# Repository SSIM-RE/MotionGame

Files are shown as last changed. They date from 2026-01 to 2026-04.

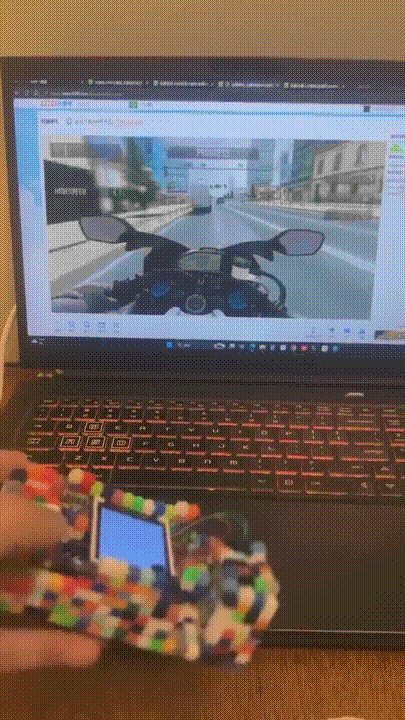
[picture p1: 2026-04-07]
img/控制.gif

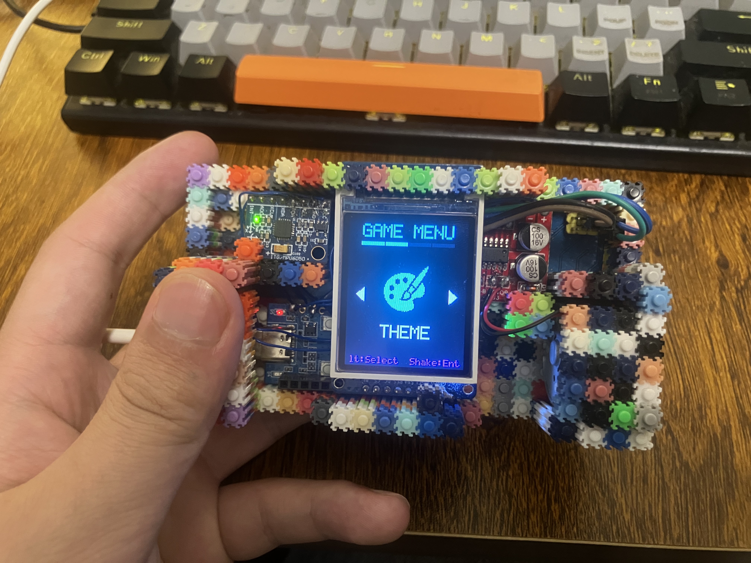
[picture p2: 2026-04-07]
img/微信图片_20260407233300_20_2.jpg

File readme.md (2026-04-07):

# MotionGame 🎮

> 基于 ESP32-C3 的体感游戏设备 + WiFi 无线键盘控制器





---

## 项目简介

MotionGame 是一款基于 ESP32-C3 的体感游戏设备，集成 MPU6050 六轴传感器，支持多款体感游戏。设备同时具备 **WiFi 无线键盘控制器** 功能，可以将倾斜、摇晃手势实时映射为键盘输入，控制 PC 上的应用程序。

---

## 硬件规格

| 组件 | 型号 | 说明 |
|---|---|---|
| MCU | ESP32-C3 | RISC-V 架构，160MHz，WiFi 内置 |
| IMU | MPU6050 | 6轴陀螺仪+加速度计，I2C 接口 |
| 屏幕 | ST7735 | 128×160 LCD，SPI 接口 |
| 震动 | L298N 马达驱动 | PWM 多段波形震动反馈 |
| 声音 | 蜂鸣器 | 多音符序列音效 |
| 供电 | USB-C | 5V/500m |

---

## 🎬 功能演示
*见img文件夹*
### 🖥️ 系统切换

系统

🖥️ 主题切换

主题

### 🎮 游戏

游戏

### ⌨️ 体感控制输入

控制

| 设备倾斜 | → | PC 按键 | 说明 |
|:---:|:-:|:---:|:-----:|
| 前倾 | → | ↑ | 向上 |
| 后倾 | → | ↓ | 向下 |
| 左倾 | → | ← | 向左 |
| 右倾 | → | → | 向右 |
| 摇晃 | → | A | 确认 |

---

## 功能模式

### 🎮 游戏模式

| 游戏 | 控制方式 | 说明 |
|---|---|---|
| 🐍 贪吃蛇 | 前后左右倾斜 | 经典贪吃蛇，体感控制方向 |
| ⚽ 平衡球 | 前后左右倾斜 | 控制小球滚动到目标区域 |
| 🏎️ 赛车 | Roll=加速/减速 Pitch=转向 | 伪3D 赛道，动态天空系统 |

### ⌨️ WiFi 控制器模式

将设备变为无线键盘，通过 UDP 发送按键事件到 PC。

| 倾斜方向 | 映射按键 |
|---|---|
| 右倾 (pitch ↑) | → (右箭头) |
| 左倾 (pitch ↓) | ← (左箭头) |
| 前倾 (roll ↑) | ↑ (上箭头) |
| 后倾 (roll ↓) | ↓ (下箭头) |
| 摇晃 | A (50ms 脉冲) |

进入模式时自动锁定基准姿态。

---

## 🏎️ 赛车游戏 - 伪3D 赛道实现详解

### 参考项目

本游戏的伪3D赛道实现参考自 [BojanSof/Pseudo3D-road](https://github.com/BojanSof/Pseudo3D-road)，核心技术原理源自 [Lou's Pseudo 3d Page](http://www.extentofthejam.com/pseudo/)。

### 1. 核心概念：什么是伪3D？

伪3D（又称 2.5D）是一种通过**伪透视变换**创造三维环境错觉的技术。与真正的3D多边形渲染不同，它通过对每一行（scanline）进行独立计算来实现深度感。

**为什么用伪3D而不是真3D多边形？**
- 计算量极低，适合 ESP32 这种资源有限的 MCU
- 独特的** warp 效果**能营造出老式街机赛车游戏的**速度感和兴奋感**
- 可以轻松创建超大赛道，无需担心空间关系

### 2. 赛道渲染原理

#### 2.1 Z-Map（深度映射表）

伪3D赛道的核心是**预计算的 Z-Map**：为屏幕的每一行计算对应的深度值（距离摄像机的远近）。

```
屏幕 Y 坐标 ──────→ 深度 Z 值
─────────────────────────────────
   0 (顶部/远处)  →  最大距离
   159 (底部/近处) →  最小距离 (clip_z)
```

本游戏使用简化的线性 Z 映射：
```c
float world_z = n * RACE_SEGMENT_LENGTH - cam_z;
// n = 赛道段索引
// RACE_SEGMENT_LENGTH = 200.0f (每段物理长度)
// cam_z = 摄像机在世界中的位置
```

#### 2.2 3D 透视投影

将 3D 世界坐标投影到 2D 屏幕坐标：

```c
// 透视投影公式
float d = 1.0f / tanf((fov * 0.5f) * M_PI / 180.0f);  // 焦距
float scale = d / world_z;                              // 缩放因子
float screen_x = (RACE_SCREEN_W / 2.0f) + (RACE_SCREEN_W / 2.0f) * world_x * scale;
float screen_y = (RACE_SCREEN_H / 2.0f) - (RACE_SCREEN_H / 2.0f) * world_y * scale;
float screen_w = (RACE_SCREEN_W / 2.0f) * (ROAD_WIDTH * scale);  // 道路宽度
```

**关键点**：
- 摄像机**灭点固定在屏幕中央**
- 视角偏移完全依赖 `world_x`（道路弯曲度 + 玩家横向位置）

#### 2.3 道路段渲染（画家算法）

从近到远绘制，每一段都是梯形四边形：

```c
drawQuad(sx1, sx2, sy1, sy2,   // 上下边缘的屏幕 X 坐标
         sw1, sw2,              // 上下边缘的半宽
         color);               // 填充颜色
```

**颜色条纹系统**：
```c
// 根据距离索引决定颜色（每3段切换一次）
uint16_t grass = (abs_idx / 3) % 2 ? GRASS1 : GRASS2;  // 草地
uint16_t road  = (abs_idx / 3) % 2 ? ROAD1  : ROAD2;   // 道路
uint16_t rum   = (abs_idx / 9) % 2 ? RUMBLE1 : RUMBLE2; // 路肩
uint16_t line  = (abs_idx / 6) % 2 ? 0 : LINE_COLOR;   // 中心线
```

### 3. 弯道实现

弯道通过**累积偏移量**实现。每段的 `curve` 值累加到道路中心线上：

```c
current_dx += prev->curve;   // 累加弯道曲率
current_x += current_dx;     // 道路中心 X 偏移

// 世界坐标系 X = -(道路累加弯曲度 + 玩家横向偏移)
float world_x = -current_x - player_x;
```

### 4. 动态 FOV（视野角度）

速度越快，FOV 越宽，增强速度感：

```c
float dynamic_fov = base_fov + (speed / max_speed) * 20.0f;
// 基础 FOV=100°，最高可到 120°
```

### 5. Procedural 赛道生成

赛道是**无限生成的**，每个赛道段包含：
- `curve`: 弯道曲率 (-8.0 ~ +8.0)
- `y`: 地形高度（上下坡）
- `object_type`: 路边景物类型（树木、棕榈树、标志牌）
- `object_side`: 景物在左侧还是右侧
- `object_scale`: 景物大小缩放

生成器使用三阶段循环：
```
阶段0: 平滑过渡到弯道 (easeInOut)
阶段1: 保持弯道
阶段2: 平滑回归直线 (easeInOut)
```

### 6. 路边景物系统

景物以**公告板（Billboard）** 方式绘制，通过几何图形模拟：

| 类型 | 绘制方式 | 参数 |
|---|---|---|
| 松树 | 三角形树冠 + 矩形树干 | 缩放比例 |
| 棕榈树 | 多层圆环几何体 | 缩放比例 |
| 路牌 | 矩形牌子 + 矩形支柱 | 侧边方向 |

景物从远到近绘制（反向画家算法），保证正确的遮挡关系。

### 7. 天空系统

动态时间系统，24小时循环：

| 时段 | 天空颜色 | 天体 |
|---|---|---|
| 0:00 - 4:00 | 深夜蓝 | 月亮 + 星星 |
| 4:00 - 6:00 | 黎明渐变 | 日出 |
| 6:00 - 18:00 | 白天 | 太阳 |
| 18:00 - 20:00 | 黄昏渐变 | 日落 |
| 20:00 - 24:00 | 夜晚 | 月亮 + 星星 |

天空 X 轴偏移与弯道联动：
```c
sky_offset -= current_curve * speed * 0.035f;
// 过弯时天空会向弯道反方向偏移
```

---

## 🎨 主题切换系统

### 6 种预设主题

| 主题 | 背景 | 主色 | 次色 | 强调色 | 适用场景 |
|---|---|---|---|---|---|
| **Classic** | 黑 | 红 | 绿 | 青 | 复古街机 |
| **Dark** | 深灰 | 蓝紫 | 浅蓝 | 深青 | 夜间使用 |
| **Light** | 白 | 浅红 | 深红 | 绿 | 明亮环境 |
| **Retro** | 黑 | 绿 | 橙红 | 青 | 80年代风 |
| **Game** | 黑 | 品红 | 青 | 品红 | 游戏主机 |
| **Tech** | 黑 | 青 | 品红 | 青 | 科技感 |

### 颜色结构体

```c
typedef struct {
    uint16_t background;   // 背景色
    uint16_t foreground;   // 前景色
    uint16_t primary;      // 主色（标题）
    uint16_t secondary;   // 次色（副标题）
    uint16_t accent;      // 强调色（高亮）
    uint16_t text;        // 文本色
    uint16_t highlight;    // 选中高亮
    uint16_t border;      // 边框色
} ThemeColors_t;
```

### 主题切换操作

| 操作 | 效果 |
|---|---|
| 左右倾斜 | 切换主题预览 |
| 摇晃 | 确认选中主题，保存到 EEPROM |
| Roll 后倾 | 取消，返回菜单（不保存） |

### EEPROM 持久化

主题设置保存在 ESP32 的 **EEPROM** 地址 0，首次启动自动读取。

```c
#define THEME_EEPROM_ADDR 0
EEPROM.put(THEME_EEPROM_ADDR, current_theme);
```

---

## 项目结构

```
MotionGame/
├── firmware/MotionGame/          # Arduino 固件
│   ├── MotionGame.ino            # 主入口
│   ├── system.cpp/h              # 状态机 (菜单→游戏→控制器)
│   ├── menu_app.cpp/h             # 主菜单
│   ├── game_select_app.cpp/h      # 游戏选择
│   ├── game_snake.cpp/h          # 贪吃蛇
│   ├── game_balance.cpp/h         # 平衡球
│   ├── game_race.cpp/h           # 赛车 (伪3D) ⭐
│   │   └── 核心渲染:
│   │       ├── project()         # 3D透视投影
│   │       ├── drawQuad()        # 四边形绘制
│   │       ├── generateNextSegment() # 赛道生成
│   │       ├── render()          # 双通道渲染
│   │       └── drawSkyGradient() # 动态天空
│   ├── wifi_controller.cpp/h      # WiFi 控制器 ⭐
│   ├── motion_service.cpp/h      # 体感识别
│   ├── display_driver.cpp/h       # LCD 驱动
│   ├── output_feedback.cpp/h      # 震动+蜂鸣器统一反馈
│   ├── motor.cpp/h               # 马达驱动
│   ├── buzzer.cpp/h              # 蜂鸣器驱动
│   └── theme_app.cpp/h           # 主题切换 ⭐
├── tools/                         # PC 端工具
│   ├── udp_keyboard.py           # UDP 键盘模拟器
│   └── requirements.txt          # Python 依赖
├── hardware/                      # 硬件设计文件
└── docs/                          # 开发文档
```

---

## 快速开始

### 1. 编译固件

**环境要求：**
- [Arduino IDE](https://www.arduino.cc/en/software) 2.x
- ESP32 核心 (通过 Board Manager 安装 `esp32`)

**步骤：**
```bash
# 克隆项目
git clone <repo-url>
cd MotionGame

# 在 Arduino IDE 中打开
#    文件 → 打开 → firmware/MotionGame/MotionGame.ino

# 选择开发板
#    工具 → 开发板 → ESP32 Arduino → ESP32C3 Dev Module

# 上传
#    烧录按钮 (→)
```

### 2. 配置 WiFi 控制器

编辑 `firmware/MotionGame/wifi_controller.h`：

```cpp
#define WIFI_SSID           "你的WiFi名称"
#define WIFI_PASSWORD       "你的WiFi密码"
#define WIFI_TARGET_IP      "192.168.101.2"    // PC 的 IP 地址
#define WIFI_TARGET_PORT    8888
```

### 3. 运行 PC 端接收器

```bash
# 安装依赖
pip install keyboard

# 运行（需要管理员权限）
python tools/udp_keyboard.py
```

---

## 游戏控制说明

### 🐍 贪吃蛇

| 动作 | 控制 |
|---|---|
| 上下移动 | 前后倾斜 |
| 左右移动 | 左右倾斜 |

### ⚽ 平衡球

| 动作 | 控制 |
|---|---|
| 球滚动方向 | 倾斜方向 |
| 目标区域 | 到达终点得分 |

### 🏎️ 赛车

| 动作 | 控制 |
|---|---|
| 加速 | Roll 前倾（倾斜度决定油门深度） |
| 减速/刹车 | Roll 后倾 |
| 左转 | Pitch 左倾 |
| 右转 | Pitch 右倾 |
| 退出游戏 | 摇晃 |

**赛车特性**：
- 无限 procedural 赛道
- 动态 FOV（速度越快视野越宽）
- 动态天空（24小时循环）
- 路边随机景物
- 离心力物理反馈
- 草地减速惩罚
- 引擎震动反馈

---

## WiFi 控制器使用指南

### 连接流程

```
1. ESP32 上电 → 显示主菜单
2. 选择 "CONTROLLER" 选项
3. ESP32 自动连接 WiFi
4. WiFi 连接成功后自动锁定基准姿态
5. 立即开始发送按键
```

### 调节灵敏度

编辑 `firmware/MotionGame/wifi_controller.h`：

```cpp
#define TILT_THRESHOLD      10.0f   // 倾斜阈值（度），值越小越灵敏
```

### UDP 协议

```
PRESS:UP       # 按下 上箭头
RELEASE:UP     # 释放 上箭头
RELEASE:ALL    # 释放所有按键
```

---

## 技术特性

### 体感识别
- 倾斜检测 (TILT_LEFT/RIGHT/FORWARD/BACK)
- 摇晃检测 (MOTION_SHAKE)
- Roll 姿态检测 (ROLL_FORWARD/BACK)

### 显示系统
- ST7735 128×160 LCD
- SPI 双缓冲，无闪烁
- 6 种主题色彩，EEPROM 持久化

### 反馈系统
- 马达：多段波形震动 (L298N 驱动)
- 蜂鸣器：多音符序列 (DO RE MI...)
- 统一 API：`Output_Feedback(FEEDBACK_EAT/HIT/DIE...)`

### WiFi 控制器
- UDP 单播直连 PC
- 实时按键映射
- 摇晃自动触发 A 键 (50ms 脉冲)

---

## 开发

### 串口调试命令（赛车游戏）

| 按键 | 功能 |
|---|---|
| W/S | 增加/减少摄像机高度 |
| R/F | 增加/减少 FOV |
| ]/[ | 增加/减少最大速度 |

### 添加新游戏

1. 在 `system_state.h` 添加新 `GameID_t`
2. 创建 `game_xxx.cpp/h`
3. 在 `game_app.cpp` 注册游戏
4. 在 `game_select_app.cpp` 添加游戏项

### 添加新按键

1. 在 `wifi_controller.h` 的 `ControllerKey_t` 添加
2. 在 `keys_to_byte()` 和 `send_key_event()` 添加映射
3. 在 Python `KEY_MAP` 添加

---

## 参考资料

- [Lou's Pseudo 3d Page](http://www.extentofthejam.com/pseudo/) - 伪3D赛道核心原理
- [Code inComplete's How to build a racing game](https://codeincomplete.com/articles/javascript-racer/) - JavaScript 赛车游戏教程
- [BojanSof/Pseudo3D-road](https://github.com/BojanSof/Pseudo3D-road) - 参考实现

---

## 更新日志

| 日期 | 内容 |
|---|---|
| 2026-04 | WiFi 控制器模式，支持 PC 键盘模拟 |
| 2026-04 | 详细伪3D赛道实现文档、主题切换系统文档 |
| 2026-03 | 震动反馈系统、游戏反馈音效 |
| 2026-02 | 赛车游戏、动态天空系统 |
| 2026-01 | 贪吃蛇、平衡球游戏 |

---

## 许可证

MIT License

## 作者

SSIM-RE

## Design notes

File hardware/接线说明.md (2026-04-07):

# MotionGame 硬件接线说明

> 本文档记录所有硬件模块的接线信息，来源：源码 `*.h` 文件中的 `#define` 定义

---

## 硬件概览

| 模块 | 型号 | 接口 | 数量 |
|---|---|---|---|
| MCU | ESP32-C3 | - | 1 |
| IMU | MPU6050 | I2C | 1 |
| 屏幕 | ST7735 | SPI | 1 |
| 蜂鸣器 | 有源蜂鸣器 | GPIO PWM | 1 |
| 马达驱动 | L298N | GPIO PWM | 1 |

---

## ESP32-C3 引脚分配表

| GPIO | 功能 | 连接的外部设备 | 说明 |
|---|---|---|---|
| **0** | PWM 输出 | 蜂鸣器 (BUZZER_PIN) | 蜂鸣器信号 |
| **2** | SPI SCK | 屏幕 ST7735 | SPI 时钟 |
| **3** | SPI MOSI | 屏幕 ST7735 | SPI 数据输出 |
| **4** | I2C SDA | MPU6050 | I2C 数据线 |
| **5** | I2C SCL | MPU6050 | I2C 时钟线 |
| **7** | SPI CS | 屏幕 ST7735 | 片选信号 |
| **8** | GPIO 输出 | L298N IN3 | 马达B PWM |
| **12** | GPIO 输出 | L298N IN1 | 马达A PWM |
| **13** | GPIO 输出 | L298N IN4 | 马达B 方向 |
| **18** | GPIO 输出 | L298N IN2 | 马达A 方向 |

---

## 详细接线

### 1. MPU6050 六轴传感器

```
ESP32-C3          MPU6050
---------         --------
GPIO 4 (SDA)  →  SDA
GPIO 5 (SCL)  →  SCL
3.3V           →  VCC
GND            →  GND
```

| MPU6050 引脚 | 连接 |
|---|---|
| VCC | 3.3V (ESP32) |
| GND | GND |
| SDA | GPIO 4 |
| SCL | GPIO 5 |
| AD0 | GND (地址 0x68) |

> ⚠️ I2C 地址为 0x68（AD0 接地）

---

### 2. ST7735 1.8" LCD 屏幕 (128x160)

```
ESP32-C3          ST7735
---------         -------
GPIO 2 (SCK)   →  SCK
GPIO 3 (MOSI)  →  SDA
GPIO 7 (CS)    →  CS
3.3V           →  VCC
GND            →  GND
```

> ⚠️ ST7735 工作电压为 3.3V，**不要连接 5V**

| ST7735 引脚 | 连接 | 说明 |
|---|---|---|
| VCC | 3.3V | 供电 |
| GND | GND | 地 |
| SCK | GPIO 2 | SPI 时钟 |
| SDA | GPIO 3 | SPI 数据 |
| CS | GPIO 7 | 片选 |
| RESET | 3.3V 或 GPIO | 复位（低电平有效） |
| AO/DC | 可不接 | 数据/命令选择 |

> 📝 SPI 初始化代码：`SPI.begin(2, -1, 3, 7)` → SCK=2, MISO=-1, MOSI=3, CS=7

---

### 3. 蜂鸣器

```
ESP32-C3          蜂鸣器
---------         --------
GPIO 0          →  信号引脚
3.3V            →  VCC (有源蜂鸣器)
GND             →  GND
```

| 蜂鸣器引脚 | 连接 |
|---|---|
| VCC | 3.3V |
| GND | GND |
| SIG | GPIO 0 (PWM) |

> 📝 PWM 配置：频率 2000Hz，分辨率 8-bit

---

### 4. L298N 马达驱动模块

```
ESP32-C3          L298N
---------         ------
GPIO 12 (IN1)  →  IN1    (马达A PWM)
GPIO 18 (IN2)  →  IN2    (马达A 方向)
GPIO 8  (IN3)  →  IN3    (马达B PWM)
GPIO 13 (IN4)  →  IN4    (马达B 方向)
5V             →  5V (逻辑电源)
GND            →  GND
```

| L298N 引脚 | 连接 | 说明 |
|---|---|---|
| IN1 | GPIO 12 | 马达A PWM 控制 |
| IN2 | GPIO 18 | 马达A 方向控制 |
| IN3 | GPIO 8 | 马达B PWM 控制 |
| IN4 | GPIO 13 | 马达B 方向控制 |
| 5V | ESP32 5V | 逻辑电源 |
| GND | ESP32 GND | 地 |
| 12V | 电池正 | 马达电源 (如果使用独立供电) |
| OUT1/OUT2 | 马达A | 连接震动马达 |
| OUT3/OUT4 | 马达B | 未使用 |

> ⚠️ L298N 需要独立的马达电源（建议 6-12V），不要直接从 ESP32 取电

---

## 接线图（文字版）

```
                    ┌─────────────────┐
                    │   ESP32-C3      │
                    │                 │
                    │  GPIO 0  ──────┼──→ 蜂鸣器 (PWM)
                    │  GPIO 2  ──────┼──→ ST7735 SCK
                    │  GPIO 3  ──────┼──→ ST7735 MOSI
                    │  GPIO 4  ──────┼──→ MPU6050 SDA
                    │  GPIO 5  ──────┼──→ MPU6050 SCL
                    │  GPIO 7  ──────┼──→ ST7735 CS
                    │  GPIO 8  ──────┼──→ L298N IN3
                    │  GPIO 12 ──────┼──→ L298N IN1
                    │  GPIO 13 ──────┼──→ L298N IN4
                    │  GPIO 18 ──────┼──→ L298N IN2
                    │                 │
                    │  3.3V    ──────┼──→ ST7735 VCC, MPU6050 VCC
                    │  5V      ──────┼──→ L298N 5V
                    │  GND     ──────┼──→ 所有 GND
                    └─────────────────┘
```

---

## I2C 地址

| 设备 | I2C 地址 | 说明 |
|---|---|---|
| MPU6050 | 0x68 | AD0 接地 |

---

## SPI 配置

| 参数 | 值 |
|---|-----|
| SCK | GPIO 2 |
| MOSI | GPIO 3 |
| MISO | 未使用 (-1) |
| CS | GPIO 7 |
| 频率 | 默认 |

---

## 电源需求

| 模块 | 电压 | 电流 | 来源 |
|---|---|---|---|
| ESP32-C3 | 3.3V / 5V | - | USB-C 输入 |
| MPU6050 | 3.3V | ~5mA | ESP32 3.3V |
| ST7735 | 3.3V | ~30mA | ESP32 3.3V |
| 蜂鸣器 | 3.3V / 5V | ~20mA | ESP32 3.3V/5V |
| L298N 逻辑 | 5V | ~30mA | ESP32 5V |
| L298N 马达 | 6-12V | ~1A | 外部电源 |

> ⚠️ 建议使用 USB-C 供电（5V/500mA）同时给 L298N 外接独立电源（7.4V 或 12V）给马达供电

---

## 源码中的引脚定义汇总

### motor.h
```cpp
#define MOTOR_A_IN1    12   // 马达A PWM
#define MOTOR_A_IN2    18   // 马达A 方向
#define MOTOR_B_IN3    8    // 马达B PWM
#define MOTOR_B_IN4    13   // 马达B 方向
```

### buzzer.h
```cpp
#define BUZZER_PIN         0
#define BUZZER_BASE_FREQ   2000
#define BUZZER_PWM_RES    8
```

### mpu6050.h
```cpp
#define SCL 5
#define SDA 4
```

### display_driver.cpp (SPI 初始化)
```cpp
SPI.begin(2, -1, 3, 7);  // SCK=2, MISO=-1, MOSI=3, CS=7
```

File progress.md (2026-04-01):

# MotionGame 进度追踪

## 项目概览
- 进度: 60% (3/5)
- 状态: 🟢 进行中
- 当前里程碑: M4 - 游戏内容开发
- 最后更新: 2026-03-30

## 里程碑

- [x] M1: 硬件基础搭建
- [x] M2: 固件框架开发
- [x] M3: 体感识别系统
- [ ] M4: 游戏内容开发 (进行中)
- [ ] M5: WiFi/云端功能

## 游戏开发进度

| 游戏 | 状态 | 说明 |
|---|---|---|
| 贪吃蛇 | ✅ 完成 | 体感控制 |
| 平衡球 | ✅ 完成 | 体感控制小球滚到终点 |

## 固件版本

| 版本 | 日期 | 更新内容 |
|---|---|---|
| v1.3 | 2026-02-18 | 平衡球游戏、云端接口、本地高分存储 |
| v1.2 | - | 框架优化、buzzer设计、动作识别 |

## 下一步任务

1. 完善俄罗斯方块游戏
2. 开发拼图游戏
3. 添加 WiFi 功能（NTP 时间同步、分数上传）
4. 添加震动反馈

## 更新记录

### 2026-03-30
- ✅ 添加 L298N 马达驱动 (motor.h, motor.cpp)
- ✅ GPIO: IN1=GPIO12, IN2=GPIO18, IN3=GPIO8, IN4=GPIO13
- ✅ PWM 调速（IN1/IN3）+ GPIO 控制（IN2/IN4）
- ✅ 震动反馈系统（震动+蜂鸣器整合）
- ✅ 统一输出反馈系统 (output_feedback.h/cpp)
- ✅ 马达多段波形 + 蜂鸣器序列播放
- ✅ 清理旧 API（audio_service, Buzzer_Play 序列）
- ✅ 迁移 game_balance.cpp 到新 API
- ✅ 修复编译错误（output.h, game_balance.cpp）
- ✅ 统一游戏文件结构：所有游戏独立文件
- ✅ game_snake.h/cpp - 贪吃蛇（已集成震动）
- ✅ game_tetris.h/cpp - 俄罗斯方块（已集成震动）
- ✅ game_balance.h/cpp - 平衡球（已有）
- ✅ game_app.h/cpp - 游戏统一入口（重构）

## 最后更新: 2026-03-30

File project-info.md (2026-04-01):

# MotionGame 技术信息

> 最后更新: 2026-03-30

---

## 硬件配置

### ESP32-C3
- 架构: RISC-V
- 特性: WiFi + Bluetooth 5.0 LE

### MPU6050
- 类型: 6轴 IMU（3轴陀螺仪 + 3轴加速度计）
- 接口: I2C
- 地址: 0x68

### LCD 128x160
- 接口: SPI
- 驱动: ST7735

### 反馈设备
- 无源蜂鸣器: 声音反馈
- 震动电机: 触觉反馈

---

## 固件架构

### 目录结构
```
firmware\MotionGame\
├── MotionGame.ino      # 主程序
└── (其他源文件)
```

### 核心模块
| 模块 | 说明 |
|---|---|
| MPU6050 | 读取姿态数据，计算倾斜角度 |
| InputSystem | 体感输入解析（倾斜/晃动检测） |
| GameEngine | 游戏循环管理 |
| DisplaySystem | 双缓冲 LCD 显示 |
| AudioSystem | 蜂鸣器音效 |
| HapticSystem | 震动反馈 |
| CloudService | 云端接口（预留） |

---

## 体感识别

### 姿态计算
- 使用 DMP（Digital Motion Processor）获取四元数
- 转换为欧拉角（Roll/Pitch/Yaw）
- 倾斜角度用于方向控制

### 动作检测
| 动作 | 检测方式 |
|---|---|
| 倾斜 | Pitch/Roll 角度超过阈值 |
| 晃动 | 加速度变化率超过阈值 |
| 点击 | 短时间大加速度峰值 |

---

## 开发环境

### 工具链
- Arduino IDE 或 PlatformIO
- ESP-IDF
- Arduino ESP32 Core

### 烧录配置
- Board: ESP32C3 Dev Module
- Baudrate: 921600
- Port: COMx

---

## 技术笔记

### 双缓冲显示
- 原理: 在内存中构建完整帧，再一次性发送到 LCD
- 避免部分刷屏导致的闪烁

### 体感校准
- 开机时静止校准零偏
- 动态补偿温度漂移

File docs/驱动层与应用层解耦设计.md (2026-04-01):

# MotionGame 驱动层与应用层解耦设计

> 本文档说明硬件底层驱动如何与应用层解耦，作为后续开发的参考。

---

## 一、整体架构

```
┌─────────────────────────────────────────────────────────────────┐
│                        应用层 (App Layer)                        │
│   menu_app | game_snake | game_balance | theme_app             │
│   ────────────────────────────────────────────────────────     │
│   业务逻辑：游戏规则、UI交互、得分系统                           │
└─────────────────────────────┬───────────────────────────────────┘
                              │ 读取 / 触发
                              ▼
┌─────────────────────────────────────────────────────────────────┐
│                      解耦层 (Abstraction Layer)                  │
│   ────────────────────────────────────────────────────────     │
│   input.h      → 统一输入入口                                   │
│   output.h     → 统一输出入口 (feedback事件)                   │
│   game_app.h   → 统一游戏接口                                   │
└─────────────────────────────┬───────────────────────────────────┘
                              │
┌─────────────────────────────┴───────────────────────────────────┐
│                       驱动层 (Driver Layer)                      │
│   ────────────────────────────────────────────────────────       │
│   mpu6050.cpp      → I2C 姿态传感器 raw 数据                   │
│   motion_service.cpp → 动作识别 (倾斜/晃动/翻滚)                │
│   display_driver.cpp → SPI LCD 128x160 双缓冲                  │
│   buzzer.cpp       → PWM 蜂鸣器                                 │
│   motor.cpp       → PWM 震动马达                               │
└─────────────────────────────────────────────────────────────────┘
```

---

## 二、输入系统 (姿态 → 应用)

### 数据流

```
MPU6050 (I2C) 
    ↓ raw数据
motion_service.cpp (每帧调用)
    ↓ 滤波 + 姿态解算 + 动作识别
IMU_me (全局结构体)
    ↓ 应用层直接读取
app层 (menu_app / game_snake)
```

### 应用层使用方式

```c
#include "motion_service.h"
#include "motion_type.h"

// 方式1: 检测动作事件 (推荐)
void GameUpdate() {
    if (IMU_me.motion == MOTION_SHAKE) {
        // 开始游戏
    }
    if (IMU_me.motion == MOTION_TILT_LEFT) {
        // 向左移动
    }
}

// 方式2: 读取原始角度 (精细控制)
void SnakeControl() {
    int8_t dir = 0;
    if (IMU_me.rel_pitch > 5) dir = 1;   // 前倾
    if (IMU_me.rel_pitch < -5) dir = -1; // 后仰
    // 控制蛇的方向
}
```

### 全局数据结构

```c
// motion_type.h
typedef struct {
    float roll, pitch;           // 角度 (deg)
    float ax, ay, az;            // 加速度 (g)
    float gx, gy, gz;             // 陀螺仪 (deg/s)
    float rel_roll, rel_pitch;   // 相对基准角度
    MotionType_t motion;         // 当前动作事件
} IMU;

extern IMU IMU_me;  // 全局单例
```

### 动作事件类型

| 事件 | 触发条件 | 用途 |
|---|---|---|
| `MOTION_TILT_RIGHT` | 前倾 > 15° | 菜单→右 / 蛇→下 |
| `MOTION_TILT_LEFT` | 后仰 < -15° | 菜单←左 / 蛇→上 |
| `MOTION_ROLL_FRONT` | 右滚 > 15° | 蛇→右 |
| `MOTION_ROLL_BACK` | 左滚 < -15° | 蛇→左 |
| `MOTION_SHAKE` | 加速度突变 | 确认 / 开始 |

---

## 三、输出系统 (应用 → 反馈)

### 数据流

```
app层 (game_snake)
    ↓ 语义化事件
output_feedback.cpp
    ↓ 解析事件
motor.cpp / buzzer.cpp
    ↓ PWM驱动
马达 / 蜂鸣器
```

### 应用层使用方式

```c
#include "output_feedback.h"

// 简单触发
void OnEatFood() {
    Output_Feedback(FEEDBACK_EAT);      // 轻震 + 短音
}

void OnHitWall() {
    Output_Feedback(FEEDBACK_HIT);     // 强震 + 警告音
}

void OnGameOver() {
    Output_Feedback(FEEDBACK_GAME_OVER); // 长震 + 结束音
}

// 精细控制
void OnMenuMove() {
    Output_MotorVibrate(100, 30);       // 马达: 速度100, 30ms
    Output_BuzzerTone(800, 50, 50);    // 蜂鸣器: 800Hz, 50ms, 50%音量
}
```

### 预定义反馈事件

```c
// ===== 组合反馈 (马达+蜂鸣器) =====
FEEDBACK_EAT        // 吃到食物
FEEDBACK_HIT       // 撞墙
FEEDBACK_DIE       // 死亡
FEEDBACK_LEVEL_UP // 升级
FEEDBACK_SUCCESS   // 成功
FEEDBACK_ERROR     // 错误
FEEDBACK_GAME_OVER // 游戏结束

// ===== 操作反馈 =====
FEEDBACK_CLICK     // 点击
FEEDBACK_SELECT    // 选中
FEEDBACK_BACK      // 返回

// ===== 纯马达 =====
FEEDBACK_RUMBLE    // 引擎轰鸣
FEEDBACK_TICK      // 时钟节拍

// ===== 纯蜂鸣器 =====
FEEDBACK_BEEP      // 提示音
FEEDBACK_MENU_MOVE // 菜单移动
```

---

## 四、显示系统 (应用 → 画面)

### 数据流

```
app层 (game_snake)
    ↓ 绘图API
display_driver.cpp
    ↓ 图形算法 + 双缓冲
frame_buffer[]
    ↓ SPI
TFT_eSPI → LCD 128x160
```

### 应用层使用方式

```c
#include "display_driver.h"

// 1. 帧周期控制
void GameLoop() {
    Display_StartFrame();     // 开始帧
    Display_ClearBuffer(BLACK);
    
    DrawBackground();
    DrawSnake();
    DrawFood();
    DrawUI();
    
    Display_EndFrame();       // 刷新屏幕
}

// 2. 基本绘图
Display_DrawPixel(x, y, color);
Display_DrawLine(x0, y0, x1, y1, color);
Display_DrawRect(x, y, w, h, color);
Display_FillRect(x, y, w, h, color);
Display_FillCircle(x, y, radius, color);

// 3. 文本绘制
TextParams_t params = {
    .font = DISPLAY_FONT_5x7,
    .color = WHITE,
    .bg_color = BLACK,
    .size = 1,
    .h_align = TEXT_ALIGN_LEFT,
    .v_align = TEXT_ALIGN_TOP,
    .transparent = true
};
Display_DrawString(x, y, "SCORE: 100", &params);
```

### API 速查

| 类别 | 函数 | 用途 |
|---|---|---|
| **帧控制** | `StartFrame/EndFrame` | 双缓冲周期 |
| **清除** | `ClearScreen/ClearBuffer` | 清屏 |
| **像素** | `DrawPixel/GetPixel` | 像素点 |
| **线条** | `DrawLine` | 直线 |
| **图形** | `Draw/FillRect/Circle/Triangle` | 填充图形 |
| **位图** | `DrawBitmap1B` | 图标/图片 |
| **文字** | `DrawString/DrawInt` | 文本/数字 |

---

## 五、开发流程

### 新增游戏的模板

```c
// my_game.h
#pragma once
#include "system_state.h"

void MyGame_Init(void);
SystemState_t MyGame_Update(void);
int MyGame_GetScore(void);

// my_game.c
#include "my_game.h"
#include "display_driver.h"
#include "motion_service.h"
#include "output_feedback.h"

void MyGame_Init(void) {
    // 初始化游戏状态
    Output_Feedback(FEEDBACK_SUCCESS);  // 开机反馈
}

SystemState_t MyGame_Update(void) {
    // 1. 读取输入
    if (IMU_me.motion == MOTION_SHAKE) {
        // 开始游戏
    }
    
    // 2. 游戏逻辑
    // ...
    
    // 3. 渲染画面
    Display_StartFrame();
    // 绘制游戏内容
    Display_EndFrame();
    
    // 4. 触发反馈
    if (hit_wall) {
        Output_Feedback(FEEDBACK_HIT);
    }
    
    return SYS_NONE;
}
```

### 注册到游戏选择

```c
// game_select_app.cpp
static const GameItem_t games[] = {
    { ICON_GAME_64, "SNAKE", "Classic Snake", GAME_SNAKE },
    { ICON_GAME_64, "BALANCE", "Tilt Ball", GAME_BALANCE },
    // 添加新游戏
    { ICON_GAME_64, "MY_GAME", "My New Game", GAME_MYGAME },
};

// system_state.h
typedef enum {
    GAME_NONE = 0,
    GAME_SNAKE = 1,
    GAME_BALANCE,
    GAME_MYGAME,  // 新增
    GAME_COUNT
} GameID_t;
```

---

## 六、关键约定

1. **全局单例**: 输入数据通过 `IMU_me` 全局访问
2. **语义化事件**: 输出使用 `FEEDBACK_xxx` 事件而非原始API
3. **帧周期**: 显示渲染必须在 `StartFrame/EndFrame` 之间
4. **周期性调用**: `loop()` 中每帧调用:
   - `MPU6050_Update()`
   - `MotionService_Update()`
   - `OutputFeedback_Update()`
   - `GameApp_Update()` / `MenuApp_Update()`

---

## 七、文件索引

| 层级 | 文件 | 职责 |
|---|---|---|
| **应用** | game_snake.cpp | 游戏逻辑 |
| **应用** | game_balance.cpp | 平衡球 |
| **应用** | menu_app.cpp | 菜单 |
| **解耦** | game_app.cpp | 游戏统一入口 |
| **解耦** | game_select_app.cpp | 游戏选择 |
| **解耦** | output_feedback.cpp | 反馈事件解析 |
| **驱动** | mpu6050.cpp | I2C传感器 |
| **驱动** | motion_service.cpp | 动作识别 |
| **驱动** | display_driver.cpp | LCD显示 |
| **驱动** | buzzer.cpp | 蜂鸣器 |
| **驱动** | motor.cpp | 震动马达 |

---

*最后更新: 2026-03-31*

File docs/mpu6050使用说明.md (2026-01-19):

非常好的问题 👍
**这一步如果理解透了，你就真正“会用 MPU6050 了”，而不是只会读数据。**

下面我**结合你现在代码里读到的 6 个数值**，一项一项讲清楚：
👉 **它们是什么、单位是什么、能拿来干嘛**

------

# 一、你现在读到的 6 个数值是哪些？

```cpp
mpu6050_raw_t {
    int16_t ax, ay, az;   // 加速度计
    int16_t gx, gy, gz;   // 陀螺仪
}
```

它们来自 MPU6050 内部的 **两种传感器**：

| 传感器 | 作用 |
| --- | --- |
| Accelerometer（加速度计） | 感知“倾斜 + 线性加速度” |
| Gyroscope（陀螺仪） | 感知“旋转角速度” |

------

# 二、加速度计 ax / ay / az 是什么？

### 1️⃣ 本质

👉 **测量的是某一轴方向上的“合加速度”**

包括：

- 重力加速度（1g）
- 人为移动、晃动的加速度

------

### 2️⃣ 单位 & 原始值含义

你现在读的是 **原始 ADC 值**（raw）

在默认配置（±2g）下：

| 数值 | 含义 |
| --- | ---- |
| 16384  | 1g |
| 0 | 0g |
| -16384 | -1g  |

📌 换算公式：

```cpp
加速度(g) = raw / 16384.0
```

------

### 3️⃣ 各轴在“静止”时应该看到什么？

假设模块平放、正面朝上：

| 轴 | 典型值 |
| ---- | --- |
| ax | ≈ 0 |
| ay | ≈ 0 |
| az | ≈ +16384 |

👉 **因为重力指向 Z 轴**

------

### 4️⃣ 能用来干嘛？

✔ 判断“倾斜方向”
✔ 判断“是否被甩动 / 摇晃”
✔ 简单体感（左右 / 前后）

❌ 不适合：

- 精确角度
- 快速旋转（会抖）

------

# 三、陀螺仪 gx / gy / gz 是什么？

### 1️⃣ 本质

👉 **测量角速度（转得有多快）**

不是角度，是：

```
°/s（每秒转多少度）
```

------

### 2️⃣ 原始值单位

默认配置（±250°/s）：

| 数值 | 含义  |
| ---- | ----- |
| 131  | 1°/s  |
| 0 | 静止  |
| -131 | -1°/s |

📌 换算公式：

```cpp
角速度(°/s) = raw / 131.0
```

------

### 3️⃣ 静止时应该是什么？

| 轴 | 值 |
| ---- | ---- |
| gx | ≈ 0  |
| gy | ≈ 0  |
| gz | ≈ 0  |

📌 实际会看到：

```
-10 ~ +10 之间波动（正常）
```

------

### 4️⃣ 能用来干嘛？

✔ 判断“旋转方向”
✔ 快速动作检测
✔ 手柄转动 / 甩动

❌ 不适合：

- 单独长期算角度（会漂）

------

# 四、为什么要“两个一起用”？

| 传感器 | 优点 | 缺点 |
| --- | --- | --- |
| 加速度计 | 稳定、不漂 | 动作时乱 |
| 陀螺仪 | 反应快 | 会漂 |

👉 **体感的核心公式**：

> **加速度管“稳态”
> 陀螺管“动态”**

所以你以后一定会看到：

```
互补滤波 / 卡尔曼滤波
```

------

# 五、结合你这个“体感游戏机”怎么用？

### 🎮 直觉映射（新手最适合）

| 动作 | 用哪个  |
| --- | --- |
| 左右倾斜 | ax |
| 前后倾斜 | ay |
| 快速甩手 | gx / gy |
| 转向 | gz |

例如：

```cpp
if (imu.ax > 8000)  // 向右倾
    move_right();

if (abs(imu.gx) > 15000) // 快速甩动
    attack();
```

| 轴 | 含义 |
| ----- | --- |
| roll  | 左右倾斜 |
| pitch | 前后倾斜 |

⚠️ 注意：
 **它们不反映“挥动速度”**，而反映的是“现在倾成什么样子”。

------

# 六、一个“立刻有感觉”的小实验（强烈推荐）

在 loop 里加：

```cpp
float ax_g = imu.ax / 16384.0;
float ay_g = imu.ay / 16384.0;
float az_g = imu.az / 16384.0;

Serial.print("G: ");
Serial.print(ax_g, 2);
Serial.print(", ");
Serial.print(ay_g, 2);
Serial.print(", ");
Serial.println(az_g, 2);
```

你会**第一次“感受到重力”** 👀

------

# 七、你现在已经站在这一步了

✔ 会读 MPU6050
✔ 知道每个数值代表什么
✔ 能映射到动作

下一步自然是：

1️⃣ **在 LCD 上画一个“倾斜指示器”**
2️⃣ **加简单滤波，去抖**
3️⃣ **开始设计游戏输入系统**

你说一句：
👉 **“下一步我想把 MPU6050 数据画到 LCD 上”**
我直接帮你写显示代码。

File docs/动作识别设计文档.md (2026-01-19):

# 动作识别设计文档

## MPU6050 基本姿态信息

### ax、ay、az（加速度）

各轴方向的**线性加速度分量**，包含重力加速度在各轴上的投影。

- 量程：±2g
- 数值范围：-32768 ~ 32767
- 单位：g

在设备**静止或低速运动**时，主要反映的是**重力方向**，可用于姿态解算。

------

### gx、gy、gz（角速度）

各轴方向的**角速度**，反映设备的旋转快慢。

- 量程：±250 °/s
- 标度：131 LSB ≈ 1 °/s

> ⚠️ 角速度更适合短时动态变化，不适合作为“晃动”或“冲击”动作的主要判别依据。

------

### roll、pitch（姿态角）

- **roll**：绕 **X 轴** 的倾斜角度
- **pitch**：绕 **Y 轴** 的倾斜角度

在当前设备逻辑坐标系下：

- X 轴：左右方向
- Y 轴：前后方向
- Z 轴：上下方向

#### 姿态角计算方式（基于加速度）

```c
// Roll：左右倾斜（X）
float roll_acc = atan2(ax, az) * RAD_TO_DEG;

// Pitch：前后倾斜（Y）
float pitch_acc = atan2(
    ay,
    sqrt(ax*ax + az*az)
) * RAD_TO_DEG;
```

> 实际工程中，roll / pitch 通常与陀螺仪角速度通过**互补滤波**进行融合，以提高动态稳定性。

------

## 基准姿态（Reference Pose）

为适应不同玩家的自然持握姿势，引入**基准姿态**概念：

- 基准姿态记录某一时刻的 roll / pitch
- 后续姿态计算均以该姿态为零点

```text
rel_roll  = roll  - ref_roll
rel_pitch = pitch - ref_pitch
```

动作识别基于 **相对姿态（rel_roll / rel_pitch）** 进行。

------

## 动作判别方式

### 1️⃣ 左右倾斜（Tilt）

**判别信号**：相对 pitch
**动作类型**：持续姿态类

| 动作 | 判别条件 |
| --- | --- |
| 向右倾斜 | `rel_pitch > +TILT_THRESHOLD_DEG` |
| 向左倾斜 | `rel_pitch < -TILT_THRESHOLD_DEG` |

- 推荐阈值：15° ~ 25°
- 动作在阈值范围内可持续存在
- 适用于方向控制、菜单选择等连续输入

------

### 2️⃣ 前后倾斜（可选扩展）

**判别信号**：相对 roll

| 动作 | 判别条件 |
| ---- | --- |
| 前倾 | `rel_roll > +ROLL_THRESHOLD_DEG` |
| 后倾 | `rel_roll < -ROLL_THRESHOLD_DEG` |

- 推荐阈值：15° ~ 25°
- 动作在阈值范围内可持续存在
- 适用于方向控制、菜单选择等连续输入

------

### 3️⃣ 晃动（Shake）

**判别信号**：加速度模长

```c
float acc_norm = sqrt(ax*ax + ay*ay + az*az);
```

- 静止状态：`acc_norm ≈ 1.0 g`
- 晃动状态：`acc_norm` 明显偏离 1g

**判别条件：**

```c
fabs(acc_norm - 1.0f) > SHAKE_ACC_THRESHOLD
```

| 参数 | 说明 |
| --- | --- |
| `SHAKE_ACC_THRESHOLD` | 推荐 0.30 ~ 0.45 g |
| 动作类型 | 瞬时冲击类 |
| 特点 | 与旋转解耦，抗误触性好 |

------

## 动作去重与冷却机制

为防止同一动作被连续触发，引入**冷却时间与去重逻辑**：

- 同一动作在冷却时间内只触发一次
- 动作消失后允许再次触发

```c
#define MOTION_COOLDOWN_MS 300
```

------

## 动作判别方式汇总表

| 动作 | 判别信号  | 类型 |
| ---- | --- | --- |
| 左倾 | rel_pitch | 持续姿态 |
| 右倾 | rel_pitch | 持续姿态 |
| 前倾 | rel_roll  | 持续姿态 |
| 后倾 | rel_roll  | 持续姿态 |
| 晃动 | acc_norm  | 冲击动作 |

------

## 设计说明（重要）

- 每个动作**只依赖一种主判别信号**
- 不混合使用加速度 / 姿态 / 角速度
- 有利于：
  - 调参
  - 排错
  - 后期游戏逻辑扩展

------

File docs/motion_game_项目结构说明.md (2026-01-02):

# MotionGame 项目结构说明文档

> 本文档用于说明 MotionGame 项目的整体软件架构、分层职责以及各模块之间的关系，便于后续维护、扩展和协作开发。

---

## 1. 项目目标

MotionGame 是一个基于 ESP32 的体感交互项目，核心目标是：

- 通过 **MPU6050 IMU** 获取姿态与动作数据
- 进行 **动作识别（倾斜 / 挥动 / 晃动）**
- 使用 **LCD** 进行实时可视化反馈
- 使用 **无源蜂鸣器** 输出音效反馈
- 采用 **非阻塞、分层清晰、可扩展** 的软件架构

---

## 2. 总体架构概览

项目采用自顶向下的分层结构：

```
MotionGame.ino
│
├── Input Layer        输入层（采集与更新）
│   └── input.*
│
├── Service Layer      服务层（算法 / 逻辑）
│   └── motion_service.*
│
├── Output Layer       输出调度层（更新驱动）
│   └── output.*
│
├── HAL / Driver       硬件抽象层
│   ├── buzzer.*
│   ├── mpu6050.*
│   └── lcd.*
│
├── Resource / Type    资源与类型定义
│   ├── audio_type.h
│   └── motion_type.h
│
└── UI Layer（可选）   显示逻辑
    └── ui.*
```

---

## 3. 各层职责说明

### 3.1 主程序层（MotionGame.ino）

**职责：**

- 系统初始化（setup）
- 主循环调度（loop）
- 连接各层模块，不实现具体业务细节

**特点：**

- 不直接访问硬件寄存器
- 不包含算法实现
- 只负责“调用顺序”和“模块协作”

---

### 3.2 Input Layer（输入层）

**文件：**
- `input.h / input.cpp`

**职责：**

- 对输入设备进行初始化
- 在 loop 中周期性更新输入数据

**当前包含：**

- MPU6050 采样与滤波更新

**设计原则：**

- 不做动作识别
- 不包含业务判断
- 仅负责“数据采集与刷新”

---

### 3.3 Service Layer（服务层）

**文件：**
- `motion_service.h / motion_service.cpp`

**职责：**

- 基于输入数据实现算法和逻辑
- 提供“事件级”或“语义级”结果

**当前实现：**

- 姿态计算结果读取
- 动作识别：
  - 倾斜（左 / 右）
  - 挥动（上 / 下）
  - 晃动
- 动作去重与冷却时间控制

**设计原则：**

- 不直接驱动输出设备
- 不关心 UI 或音效如何实现
- 返回“动作事件”供上层使用

---

### 3.4 Output Layer（输出调度层）

**文件：**
- `output.h / output.cpp`

**职责：**

- 对输出设备的 Update 进行统一调度

**当前包含：**

- Buzzer 的非阻塞更新驱动

**说明：**

Output 层本身不包含输出逻辑，仅作为 HAL 的更新入口，保证主循环结构清晰。

---

### 3.5 HAL / Driver Layer（硬件抽象层）

#### 3.5.1 蜂鸣器（buzzer.*）

**职责：**

- 无源蜂鸣器 PWM 驱动
- 连续音阶的非阻塞播放
- 音符状态机管理

**特性：**

- Play / Update / Stop / IsPlaying 接口
- 内部维护音符序列播放状态
- 与 Arduino-ESP32 3.x LEDC API 兼容

---

#### 3.5.2 MPU6050（mpu6050.*）

**职责：**

- IMU 原始数据读取
- 低通滤波
- 姿态解算（互补滤波）

**对外接口：**

- 加速度（g）
- 角速度（deg/s）
- 姿态角（deg）

---

#### 3.5.3 LCD（lcd.*）

**职责：**

- LCD 初始化与控制
- 提供基础绘制接口

**说明：**

LCD 层只提供“画什么”的能力，不包含 UI 逻辑。

---

### 3.6 Resource / Type Layer（资源与类型）

**文件：**
- `audio_type.h`
- `motion_type.h`

**职责：**

- 定义跨模块共享的数据结构
- 定义枚举、阈值、常量

**特点：**

- 不包含任何逻辑代码
- 只作为“公共协议”存在

---

### 3.7 UI Layer（可选）

**文件：**
- `ui.h / ui.cpp`

**职责：**

- 基于 LCD 绘制 UI 内容
- 示例：运行时间显示、简单界面

---

## 4. 主循环调用流程

```
loop():
  Input_Update();
  MotionService_Update();
  Audio_Play(若有动作事件);
  Output_Update();
```

**特点：**

- 所有模块均为非阻塞设计
- Update 驱动，利于扩展

---

## 5. 设计原则总结

- 分层清晰，职责单一
- HAL 不包含业务语义
- Service 不直接操作硬件
- 表驱动、状态机优先
- 避免 delay，使用 Update + millis

---

## 6. 后续可扩展方向

- 引入 GameService（动作 → 行为 → 反馈）
- 音效优先级与队列管理
- UI 状态机
- 多输入设备支持

---

> 本文档反映的是项目当前阶段的真实结构，随着功能演进可持续更新。

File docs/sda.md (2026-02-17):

#include "output.h"
#include "input.h"
#include "motion_service.h"
#include "motion_type.h"
#include "audio_service.h"
#include "audio_type.h"
#include "lcd.h"
#include "motion_debug_ui.h"
#include "motion_debug_serial.h"
#include "menu_service.h"
void setup() {				
    Serial.begin(115200);
    lcd_init();
    Input_Init();
    Output_Init();
    lcd_draw_dot(64, 80);
    MotionDebugUI_Init();
    MotionService_Init();
    MotionDebugSerial_Init();
    MenuService_Init();
}

void loop() {

    Input_Update();

    MotionType_t motion = MotionService_Update();
    if (motion != MOTION_NONE)
    {
        MotionDebugSerial_OnMotion(motion);
        MotionDebugUI_Update();   // ← 调试可视化
        Audio_Play(BUZZER_ATTACK);
          // 串口连续数据

    }
    MotionDebugSerial_Update();  
    MenuService_Update(motion);
    MenuService_Render();

    Output_Update();
    delay(20);
}
    // Input_Update();
    // MotionType_t motion = MotionService_Update();

    // if (motion != MOTION_NONE)
    // {
    //     MotionDebugSerial_OnMotion(motion);
    //     //MotionDebugUI_Update();   // ← 调试可视化
    //     Audio_Play(BUZZER_ATTACK);
    //       // 串口连续数据

    // }
    // //MotionDebugSerial_Update();  
    // Output_Update();
    // delay(20);

 SPI.begin(

  2,  // SCLK

  -1,  // MISO

  3,  // MOSI

  7   // CS

 );

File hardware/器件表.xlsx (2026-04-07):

MCU | 合宙esp32c3
陀螺仪 | MPU-6050
电机驱动 | L298N
马达 | R300震动马达
无源蜂鸣器 | 自制板卡
LCD | 128X160 TFT_LCD

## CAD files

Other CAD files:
hardware/Schematic1/P1.dxf

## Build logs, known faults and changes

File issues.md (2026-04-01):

# MotionGame 问题记录

## 未解决问题

### [ISSUE-003] GPIO19 可能与 USB-JTAG 冲突
- 优先级: P2
- 状态: ⚠️ 需验证
- 描述: GPIO19 默认用于 USB-JTAG，需要确认是否能正常作为 GPIO 使用
- 解决方案: 测试时观察，如有问题可更换到其他 GPIO

### [ISSUE-002] WiFi 联网功能未实现
- 优先级: P2
- 状态: ⏳ 待处理
- 描述: 云端接口已预留框架，但 WiFi 连接和 MQTT 通信未实现
- 解决方案: 实现 WiFi 连接、NTP 时间同步、分数上传

## 已解决问题

### [RESOLVED-004] 精简游戏列表
- 解决时间: 2026-03-31
- 解决方案: 只保留贪吃蛇和平衡球，移除未实现的俄罗斯方块/拼图/像素鸟

### [RESOLVED-001] 平衡球游戏开发
- 解决时间: 2026-02-18
- 解决方案: 实现了完整的体感控制小球滚动到终点的功能

### [RESOLVED-002] MPU6050 姿态读取
- 解决时间: 2026-01-24
- 解决方案: 配置 I2C 通信，读取陀螺仪和加速度计数据

### [RESOLVED-003] 双缓冲显示
- 解决时间: 2026-01-24
- 解决方案: 实现双缓冲避免 LCD 显示闪烁

## 风险清单

### [RISK-001] ESP32-C3 资源限制
- 风险等级: 中
- 描述: ESP32-C3 资源有限，多游戏可能占用过多内存
- 应对策略: 优化代码结构，按需加载游戏资源

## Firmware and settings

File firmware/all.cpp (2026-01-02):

//audio_service.cpp文件如下：
#include "buzzer.h"

static const BuzzerNote attack_notes[] = {
    { NOTE_E5, 60, 60 },
    { NOTE_G5, 70, 60 },
    { NOTE_A5, 80, 80 },
    { NOTE_E5, 60, 60 },
    { NOTE_G5, 70, 60 },
    { NOTE_A5, 80, 80 }   
};

static const BuzzerNote hit_notes[] = {
    { NOTE_C5, 80, 100 },
    { NOTE_G4, 60, 120 },
};

static const BuzzerNote startup_notes[] = {
    { NOTE_C4, 40, 80 },
    { NOTE_E4, 50, 80 },
    { NOTE_G4, 60, 80 },
    { NOTE_C5, 70, 120 },
};

static const BuzzerSequence buzzer_table[] = {
    { attack_notes,  sizeof(attack_notes)  / sizeof(BuzzerNote) },
    { hit_notes,     sizeof(hit_notes)     / sizeof(BuzzerNote) },
    { startup_notes, sizeof(startup_notes) / sizeof(BuzzerNote) },
};
void Audio_Play(BuzzerSound sound)
{
    if (sound >= BUZZER_SOUND_COUNT) return;
        Buzzer_Play(&buzzer_table[sound]);
}

bool Audio_isPlaying(BuzzerSound sound)
{
    return Buzzer_isPlaying();
}

bool Audio_Stop(BuzzerSound sound)
{
    Buzzer_Stop();
}
//audio_service.h文件如下：
#pragma once
#include <Arduino.h>
#include "audio_type.h"
void Audio_Play(BuzzerSound sound);
bool Audio_isPlaying(BuzzerSound sound);
bool Audio_Stop(BuzzerSound sound);
//audio_type.h文件如下：
#pragma once
typedef struct {
    uint16_t freq;      // Hz
    uint8_t  volume;    // 0~100
    uint16_t duration;  // ms
} BuzzerNote;

typedef struct {
    const BuzzerNote* notes;
    uint8_t count;
} BuzzerSequence;

/* ================= 音阶定义 ================= */
#define NOTE_C4  262
#define NOTE_D4  294
#define NOTE_E4  330
#define NOTE_F4  349
#define NOTE_G4  392
#define NOTE_A4  440
#define NOTE_B4  494

#define NOTE_C5  523
#define NOTE_D5  587
#define NOTE_E5  659
#define NOTE_F5  698
#define NOTE_G5  784
#define NOTE_A5  880

#define NOTE_REST 0
/* ================= 音效类型 ================= */
typedef enum {
    BUZZER_ATTACK = 0,
    BUZZER_HIT,
    BUZZER_STARTUP,
    BUZZER_SOUND_COUNT
} BuzzerSound;

//buzzer.cpp文件如下：
#include "buzzer.h"
/* ================= 工具函数 ================= */
static uint8_t volume_to_duty(uint8_t volume)
{
    if (volume > 100) volume = 100;
    return map(volume, 0, 100, 0, 255);
}

/* ================= 音效资源 ================= */

/* ================= 播放状态 ================= */
static const BuzzerSequence* current_seq = nullptr;
static uint8_t note_index = 0;
static uint32_t note_deadline = 0;
static bool playing = false;

/* ================= 初始化 ================= */
void Buzzer_Init(void)
{
    /* Arduino-ESP32 3.x 正确方式 */
    ledcAttach(BUZZER_PIN, BUZZER_BASE_FREQ, BUZZER_PWM_RES);
    ledcWrite(BUZZER_PIN, 0);   // 静音
}

/* ================= 停止 ================= */
void Buzzer_Stop(void)
{
    ledcWrite(BUZZER_PIN, 0);
    playing = false;
}

/* ================= 触发音效 ================= */
void Buzzer_Play(const BuzzerSequence* sound)
{
    current_seq = sound;
    note_index = 0;
    playing = true;

    const BuzzerNote* n = &current_seq->notes[0];

    if (n->freq == NOTE_REST) {
        ledcWrite(BUZZER_PIN, 0);
    } else {
        ledcWriteTone(BUZZER_PIN, n->freq);
        ledcWrite(BUZZER_PIN, volume_to_duty(n->volume));
    }

    note_deadline = millis() + n->duration;
}

/* ================= 非阻塞更新 ================= */
void Buzzer_Update(void)
{
    if (!playing || !current_seq) return;
    if (millis() < note_deadline) return;

    note_index++;

    if (note_index >= current_seq->count) {
        Buzzer_Stop();
        return;
    }

    const BuzzerNote* n = &current_seq->notes[note_index];

    if (n->freq == NOTE_REST) {
        ledcWrite(BUZZER_PIN, 0);
    } else {
        ledcWriteTone(BUZZER_PIN, n->freq);
        ledcWrite(BUZZER_PIN, volume_to_duty(n->volume));
    }

    note_deadline = millis() + n->duration;
}
bool Buzzer_isPlaying(void)
{
    return playing;
}
//input.cpp文件如下：
#include "input.h"
#include "mpu6050.h"
//#include "motion_detect.h"

void Input_Init(void)
{
    MPU6050_Init();
    //MotionDetect_Init();
}

void Input_Update(void)
{
    MPU6050_Update();
   // MotionDetect_Update();
}
//input.h文件如下：
#pragma once
#include <Arduino.h>
#include "mpu6050.h"
/* 输入层初始化 */
void Input_Init(void);

/* 输入层周期更新（loop 中调用） */
void Input_Update(void);
//lcd.cpp文件如下：
#include "lcd.h"

#include <Adafruit_GFX.h>
#include <Adafruit_ST7735.h>
#include <SPI.h>

/* ===== 硬件引脚 ===== */
#define TFT_CS   7
#define TFT_RST  10
#define TFT_DC   6
#define TFT_MOSI 3
#define TFT_SCLK 2

/* ===== 颜色定义 ===== */
#define LCD_BLACK   0x0000
#define LCD_YELLOW  0x07FF
#define LCD_TEXT    LCD_BLACK
#define LCD_BG      LCD_YELLOW
#define Display_Color_Black    0x0000    //黑色
#define Display_Color_Red      0x001F    //红色
#define Display_Color_Blue     0xF800    //蓝色
#define Display_Color_Green    0x07E0    //绿色
#define Display_Color_Yellow   0x07FF    //黄色
#define Display_Color_Magenta  0xF81F    //洋红
#define Display_Color_Cyan     0xFFE0    //青色
#define Display_Color_White    0xFFFF    //白色

#define DOT_RADIUS 3
#define BG_COLOR Display_Color_White
#define DOT_COLOR Display_Color_Red


static Adafruit_ST7735 tft =
  Adafruit_ST7735(TFT_CS, TFT_DC, TFT_MOSI, TFT_SCLK, TFT_RST);

void lcd_init(void) {
  tft.initR(INITR_BLACKTAB);
  tft.setFont();
  tft.setTextSize(1);
  tft.fillScreen(LCD_BG);
  tft.setTextColor(LCD_TEXT, LCD_BG);
}

void lcd_enable(bool on) {
  tft.enableDisplay(on);
}

void lcd_clear(uint16_t color) {
  tft.fillScreen(color);
}

void lcd_set_cursor(int x, int y) {
  tft.setCursor(x, y);
}

void lcd_set_text_color(uint16_t fg, uint16_t bg) {
  tft.setTextColor(fg, bg);
}

void lcd_print(const char* text) {
  tft.print(text);
}
void lcd_draw_dot(int x, int y) {
    tft.fillCircle(x, y, DOT_RADIUS, DOT_COLOR);
}

void lcd_clear_dot(int x, int y) {
    tft.fillCircle(x, y, DOT_RADIUS, BG_COLOR);
}
//lcd.h文件如下：
#pragma once
#include <stdint.h>
#include <stdbool.h>

void lcd_init(void);
void lcd_enable(bool on);

void lcd_clear(uint16_t color);
void lcd_set_cursor(int x, int y);
void lcd_set_text_color(uint16_t fg, uint16_t bg);
void lcd_print(const char* text);
void lcd_draw_dot(int x, int y);
void lcd_clear_dot(int x, int y);
//motion_service.cpp文件如下：
#include "motion_service.h"
#include "input.h"
#include <math.h>



/* ================= 内部状态 ================= */
IMU IMU_me ;
static MotionType_t last_motion = MOTION_NONE;
static uint32_t last_motion_time = 0;

/* ================= 初始化 ================= */

void MotionService_Init(void)
{
    last_motion = MOTION_NONE;
    last_motion_time = 0;
}

/* ================= 内部工具 ================= */

static bool MotionCooldownPassed(void)
{
    return (millis() - last_motion_time) > MOTION_COOLDOWN_MS;
}

/* ================= 核心更新 ================= */

MotionType_t MotionService_Update(void)
{
    float roll, pitch;
    float gx, gy, gz;

    MPU6050_GetAngle(&roll, &pitch);
    MPU6050_GetGyro(&gx, &gy, &gz);
    MPU6050_GetAngle(&IMU_me.roll, &IMU_me.pitch);
    MPU6050_GetAccel(&IMU_me.ax, &IMU_me.ay, &IMU_me.az);
    MPU6050_GetGyro(&IMU_me.gx, &IMU_me.gy, &IMU_me.gz);  
    MotionType_t detected = MOTION_NONE;

    /* ---------- 倾斜检测 ---------- */
    if (roll > TILT_THRESHOLD_DEG)
    {
        detected = MOTION_TILT_RIGHT;
    }
    else if (roll < -TILT_THRESHOLD_DEG)
    {
        detected = MOTION_TILT_LEFT;
    }

    /* ---------- 挥动检测 ---------- */
    else if (gy > SWING_GYRO_THRESHOLD)
    {
        detected = MOTION_SWING_UP;
    }
    else if (gy < -SWING_GYRO_THRESHOLD)
    {
        detected = MOTION_SWING_DOWN;
    }

    /* ---------- 晃动检测 ---------- */
    else if (fabs(gx) > SHAKE_GYRO_THRESHOLD ||
             fabs(gy) > SHAKE_GYRO_THRESHOLD)
    {
        detected = MOTION_SHAKE;
    }

    /* ---------- 去重 & 冷却 ---------- */
    if (detected != MOTION_NONE)
    {
        if (detected != last_motion && MotionCooldownPassed())
        {
            last_motion = detected;
            last_motion_time = millis();
            return detected;   // 只在“新动作”时返回
        }
    }
    else
    {
        /* 动作结束，允许下次触发 */
        last_motion = MOTION_NONE;
    }

    return MOTION_NONE;
}
//motion_service.h文件如下：
#pragma once
#include <Arduino.h>
#include "motion_type.h"

/* ================= 接口 ================= */
extern IMU IMU_me ;
/* 初始化（在 setup 调用） */
void MotionService_Init(void);

/* 更新（在 loop 中周期调用）
 * 返回：本周期检测到的“新动作事件”
 */
MotionType_t MotionService_Update(void);
//motion_type.h文件如下：
#pragma once
/* ================= 参数配置 ================= */

/* 倾斜阈值（角度） */
#define TILT_THRESHOLD_DEG        20.0f

/* 挥动阈值（角速度 deg/s） */
#define SWING_GYRO_THRESHOLD      180.0f

/* 晃动阈值 */
#define SHAKE_GYRO_THRESHOLD      250.0f

/* 动作最小间隔（ms）——防止重复触发 */
#define MOTION_COOLDOWN_MS        300

/* ================= 动作类型定义 ================= */

typedef enum
{
    MOTION_NONE = 0,

    MOTION_TILT_LEFT,
    MOTION_TILT_RIGHT,

    MOTION_SWING_UP,
    MOTION_SWING_DOWN,

    MOTION_SHAKE,

} MotionType_t;

typedef struct {
    float roll; 
    float pitch;
    float ax;
    float ay;
    float az;
    float gx;
    float gy;
    float gz;
} IMU;
//MotionGame.ino文件如下：
#include "output.h"
#include "input.h"
#include "motion_service.h"
#include "motion_type.h"
#include "audio_service.h"
#include "audio_type.h"
#include "lcd.h"

void setup() {
    Serial.begin(115200);
    lcd_init();
    Input_Init();
    Output_Init();
    lcd_draw_dot(64, 80);
}

void loop() {
    Input_Update();



    // 映射到屏幕
    int x = 64 + IMU_me.ax  * 50;
    int y = 80 + IMU_me.ay * 50;   // 注意 Y 轴反向
    int last_x =64;
    int last_y =80;
    x = constrain(x, 10, 118);
    y = constrain(y, 10, 150);

    // 擦除旧点
    lcd_clear_dot(last_x, last_y);

    // 画新点
    lcd_draw_dot(x, y);
    last_x = x;
    last_y = y;


    MotionType_t motion = MotionService_Update();
    if (motion != MOTION_NONE)
    {
        Serial.println(motion);
        Audio_Play(BUZZER_ATTACK);
    }
    Output_Update();
    delay(20);
}
//mpu6050.cpp文件如下：
#include "mpu6050.h"
#include <Wire.h>
#include <math.h>

/* ================== MPU6050 寄存器 ================== */
#define MPU6050_ADDR       0x68
#define REG_PWR_MGMT_1     0x6B
#define REG_ACCEL_XOUT_H   0x3B
#define REG_GYRO_XOUT_H    0x43

/* ================== 参数配置 ================== */
#define ACC_SCALE   16384.0f   // ±2g
#define GYRO_SCALE  131.0f     // ±250 dps

#define LPF_ALPHA  0.8f        // 低通滤波系数（0.7~0.9 常用）

/* ================== 内部状态（私有） ================== */
static float acc_f[3]  = {0};
static float gyro_f[3] = {0};

static float roll_f  = 0.0f;
static float pitch_f = 0.0f;

static uint32_t last_update_ms = 0;

/* ================== 工具函数 ================== */
static inline float lpf(float prev, float input)
{
    return LPF_ALPHA * prev + (1.0f - LPF_ALPHA) * input;
}

static int16_t read16(uint8_t reg)
{
    Wire.beginTransmission(MPU6050_ADDR);
    Wire.write(reg);
    Wire.endTransmission(false);
    Wire.requestFrom(MPU6050_ADDR, (uint8_t)2);

    return (Wire.read() << 8) | Wire.read();
}

/* ================== 初始化 ================== */
void MPU6050_Init(void)
{
    Wire.begin(SDA,SCL);

    Wire.beginTransmission(MPU6050_ADDR);
    Wire.write(REG_PWR_MGMT_1);
    Wire.write(0x00);   // 唤醒
    Wire.endTransmission();

    delay(100);
    last_update_ms = millis();
}

/* ================== 周期更新 ================== */
void MPU6050_Update(void)
{
    uint32_t now = millis();
    float dt = (now - last_update_ms) * 0.001f;
    if (dt <= 0.0f || dt > 0.1f) dt = 0.01f;
    last_update_ms = now;

    /* ---- 读取原始数据 ---- */
    int16_t ay_raw = read16(REG_ACCEL_XOUT_H);
    int16_t ax_raw = read16(REG_ACCEL_XOUT_H + 2);
    int16_t az_raw = read16(REG_ACCEL_XOUT_H + 4);

    int16_t gx_raw = read16(REG_GYRO_XOUT_H);
    int16_t gy_raw = read16(REG_GYRO_XOUT_H + 2);
    int16_t gz_raw = read16(REG_GYRO_XOUT_H + 4);

    /* ---- 单位转换 ---- */
    float ax = ax_raw / ACC_SCALE;
    float ay = ay_raw / ACC_SCALE;
    float az = az_raw / ACC_SCALE;

    float gx = gx_raw / GYRO_SCALE;
    float gy = gy_raw / GYRO_SCALE;
    float gz = gz_raw / GYRO_SCALE;

    /* ---- 低通滤波 ---- */
    acc_f[0]  = lpf(acc_f[0], ax);
    acc_f[1]  = lpf(acc_f[1], ay);
    acc_f[2]  = lpf(acc_f[2], az);

    gyro_f[0] = lpf(gyro_f[0], gx);
    gyro_f[1] = lpf(gyro_f[1], gy);
    gyro_f[2] = lpf(gyro_f[2], gz);

    /* ---- 姿态解算（互补滤波）---- */
    float roll_acc  = atan2(acc_f[1], acc_f[2]) * RAD_TO_DEG;
    float pitch_acc = atan2(-acc_f[0],
                        sqrt(acc_f[1]*acc_f[1] + acc_f[2]*acc_f[2])) * RAD_TO_DEG;

    roll_f  = 0.98f * (roll_f  + gyro_f[0] * dt) + 0.02f * roll_acc;
    pitch_f = 0.98f * (pitch_f + gyro_f[1] * dt) + 0.02f * pitch_acc;
}

/* ================== 对外接口 ================== */
void MPU6050_GetAccel(float* ax, float* ay, float* az)
{
    *ax = acc_f[0];
    *ay = acc_f[1];
    *az = acc_f[2];
}

void MPU6050_GetGyro(float* gx, float* gy, float* gz)
{
    *gx = gyro_f[0];
    *gy = gyro_f[1];
    *gz = gyro_f[2];
}

void MPU6050_GetAngle(float* roll, float* pitch)
{
    *roll  = roll_f;
    *pitch = pitch_f;
}
//mpu6050.h文件如下：
#pragma once
#include <Arduino.h>

#define SCL 5
#define SDA 4

/* ========== 初始化 & 更新 ========== */
void MPU6050_Init(void);
void MPU6050_Update(void);   // 必须周期性调用（如 100~500Hz）

/* ========== 对外数据接口（已滤波） ========== */
void MPU6050_GetAccel(float* ax, float* ay, float* az); // g
void MPU6050_GetGyro(float* gx, float* gy, float* gz);  // deg/s
void MPU6050_GetAngle(float* roll, float* pitch);       // deg
//output.h文件如下：
#pragma once
#include <stdint.h>
#include "buzzer.h"


void Output_Init(void);
void Output_Update(void);
//output.cpp文件如下：
#include "buzzer.h"
#include "output.h"


void Output_Init(void) {
    Buzzer_Init();

}

void Output_Update(void) {
    Buzzer_Update();
}
//ui.cpp文件如下：
#include "ui.h"
#include "lcd.h"
#include <Arduino.h>
#include <string.h>
#include <stdio.h>

static char oldTime[16] = {0};

void ui_init(void) {
  lcd_clear(0x07FF);
}

void ui_draw_uptime(void) {
  unsigned long sec = millis() / 1000;

  unsigned long d = sec / 86400;
  sec %= 86400;
  unsigned long h = sec / 3600;
  sec %= 3600;
  unsigned long m = sec / 60;
  sec %= 60;

  char buf[16];
  sprintf(buf, "%lu %02lu:%02lu:%02lu", d, h, m, sec);

  if (strcmp(buf, oldTime) != 0) {
    lcd_set_cursor(10, 80);
    lcd_print(oldTime);   // 擦除
    lcd_set_cursor(10, 80);
    lcd_print(buf);
    strcpy(oldTime, buf);
  }
}
//ui.h文件如下：
#pragma once
void ui_init(void);
void ui_draw_uptime(void);

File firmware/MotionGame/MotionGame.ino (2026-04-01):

#include "output.h"
#include "input.h"
#include "motion_service.h"
#include "motion_type.h"
#include "motion_debug_serial.h"
#include "system.h"
#include "motion_service.h"
#include "display_driver.h"
#include "output_feedback.h"
#include "motor.h"
void setup() {
    Serial.begin(115200);
    Input_Init();
    Output_Init();
    MotionService_Init();
    Display_Init();
    System_Init();
    //MotionDebugSerial_Init();
}
void loop() {

    Input_Update();
    System_Update();
    //MotionDebugSerial_Update();  
    Output_Update();
    
}
 

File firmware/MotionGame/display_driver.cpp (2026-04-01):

// display_driver.cpp - 增强版显示驱动
#include "display_driver.h"
#include <TFT_eSPI.h>
#include <stdarg.h>
#include <stdio.h>
#include <string.h>
#include <math.h>
#include "font_data.h"
#include <Arduino.h>

// 添加swap函数
template <typename T>
static void swap(T& a, T& b) {
    T temp = a;
    a = b;
    b = temp;
}

// ==================== 全局变量 ====================
static TFT_eSPI tft;                                // TFT驱动实例
static uint16_t frame_buffer[128 * 160];           // 双缓冲帧缓冲区
static bool double_buffer_enabled = true;          // 双缓冲启用标志

// 文本参数
static TextParams_t text_params = {
    .font = DISPLAY_FONT_5x7,
    .color = TFT_WHITE,
    .bg_color = TFT_BLACK,
    .size = 1,
    .h_align = TEXT_ALIGN_LEFT,
    .v_align = TEXT_ALIGN_TOP,
    .transparent = false
};

// ==================== 私有辅助函数 ====================

// 边界检查函数
static bool checkBounds(int x, int y) {
    return (x >= 0 && x < 128 && y >= 0 && y < 160);
}

static bool checkRectBounds(int x, int y, int w, int h) {
    return (x < 128 && y < 160 && x + w > 0 && y + h > 0);
}

// 计算裁剪后的矩形
static void clipRect(int* x, int* y, int* w, int* h) {
    if (*x < 0) { *w += *x; *x = 0; }
    if (*y < 0) { *h += *y; *y = 0; }
    if (*x + *w > 128) *w = 128 - *x;
    if (*y + *h > 160) *h = 160 - *y;
}

// 颜色混合函数
static uint16_t blendColors(uint16_t color1, uint16_t color2, float alpha) {
    if (alpha <= 0.0f) return color1;
    if (alpha >= 1.0f) return color2;
    
    uint8_t r1 = (color1 >> 11) & 0x1F;
    uint8_t g1 = (color1 >> 5) & 0x3F;
    uint8_t b1 = color1 & 0x1F;
    
    uint8_t r2 = (color2 >> 11) & 0x1F;
    uint8_t g2 = (color2 >> 5) & 0x3F;
    uint8_t b2 = color2 & 0x1F;
    
    uint8_t r = (uint8_t)(r1 + (r2 - r1) * alpha);
    uint8_t g = (uint8_t)(g1 + (g2 - g1) * alpha);
    uint8_t b = (uint8_t)(b1 + (b2 - b1) * alpha);
    
    return (r << 11) | (g << 5) | b;
}

// ==================== 初始化函数 ====================

void Display_Init(void) {
    SPI.begin(2, -1, 3, 7);
    tft.init();
    tft.setRotation(2);
    tft.fillScreen(TFT_BLACK);
    
    // 初始化双缓冲
    Display_ClearBuffer(TFT_BLACK);
    Display_EndFrame();  // 立即显示
    
    Serial.println("Display initialized (128x160, Double Buffer)");
}

// ==================== 双缓冲控制函数 ====================

void Display_SetDoubleBufferEnabled(bool enabled) {
    double_buffer_enabled = enabled;
    Serial.printf("Double buffer %s\n", enabled ? "enabled" : "disabled");
}

bool Display_GetDoubleBufferEnabled(void) {
    return double_buffer_enabled;
}

void Display_StartFrame(void) {
    // 开始新的一帧
}

void Display_EndFrame(void) {
    if (double_buffer_enabled) {
        tft.startWrite();
        tft.setAddrWindow(0, 0, 128, 160);
        tft.pushColors(frame_buffer, 128 * 160, true);
        tft.endWrite();
    }
}

void Display_ClearScreen(uint16_t color) {
    if (double_buffer_enabled) {
        Display_ClearBuffer(color);
        Display_EndFrame();
    } else {
        tft.fillScreen(color);
    }
}

void Display_ClearBuffer(uint16_t color) {
    if (double_buffer_enabled) {
        for (int i = 0; i < 128 * 160; i++) {
            frame_buffer[i] = color;
        }
    } else {
        tft.fillScreen(color);
    }
}

// ==================== 高级绘图函数 ====================

void Display_DrawPixelAlpha(int x, int y, uint16_t color, float alpha) {
    if (!checkBounds(x, y)) return;
    
    if (alpha >= 1.0f) {
        Display_DrawPixel(x, y, color);
    } else if (alpha > 0.0f) {
        if (double_buffer_enabled) {
            uint16_t bg_color = frame_buffer[y * 128 + x];
            uint16_t blended = blendColors(bg_color, color, alpha);
            frame_buffer[y * 128 + x] = blended;
        } else {
            // 直接模式下无法混合
            Display_DrawPixel(x, y, color);
        }
    }
}

void Display_DrawLineDashed(int x0, int y0, int x1, int y1, uint16_t color, uint8_t pattern) {
    int dx = abs(x1 - x0);
    int dy = abs(y1 - y0);
    int sx = (x0 < x1) ? 1 : -1;
    int sy = (y0 < y1) ? 1 : -1;
    int err = dx - dy;
    int step = 0;
    
    while (true) {
        if ((pattern >> (step % 8)) & 0x01) {
            Display_DrawPixel(x0, y0, color);
        }
        step++;
        
        if (x0 == x1 && y0 == y1) break;
        
        int e2 = 2 * err;
        if (e2 > -dy) {
            err -= dy;
            x0 += sx;
        }
        if (e2 < dx) {
            err += dx;
            y0 += sy;
        }
    }
}

void Display_DrawRoundRect(int x, int y, int w, int h, int radius, uint16_t color) {
    if (radius < 0) radius = 0;
    if (radius > w/2) radius = w/2;
    if (radius > h/2) radius = h/2;
    
    // 绘制四角圆弧
    Display_DrawCircleQuarter(x + radius, y + radius, radius, 0b1000, color); // 左上
    Display_DrawCircleQuarter(x + w - radius, y + radius, radius, 0b0100, color); // 右上
    Display_DrawCircleQuarter(x + w - radius, y + h - radius, radius, 0b0010, color); // 右下
    Display_DrawCircleQuarter(x + radius, y + h - radius, radius, 0b0001, color); // 左下
    
    // 绘制直线部分
    Display_DrawLine(x + radius, y, x + w - radius, y, color); // 上边
    Display_DrawLine(x + radius, y + h - 1, x + w - radius, y + h - 1, color); // 下边
    Display_DrawLine(x, y + radius, x, y + h - radius, color); // 左边
    Display_DrawLine(x + w - 1, y + radius, x + w - 1, y + h - radius, color); // 右边
}

void Display_FillRoundRect(int x, int y, int w, int h, int radius, uint16_t color) {
    if (radius < 0) radius = 0;
    if (radius > w/2) radius = w/2;
    if (radius > h/2) radius = h/2;
    
    // 填充中间矩形
    Display_FillRect(x + radius, y, w - 2 * radius, h, color);
    
    // 填充四个边的矩形
    Display_FillRect(x, y + radius, radius, h - 2 * radius, color);
    Display_FillRect(x + w - radius, y + radius, radius, h - 2 * radius, color);
    
    // 填充四个角的圆角
    Display_FillCircleQuarter(x + radius, y + radius, radius, 0b1000, color);
    Display_FillCircleQuarter(x + w - radius, y + radius, radius, 0b0100, color);
    Display_FillCircleQuarter(x + w - radius, y + h - radius, radius, 0b0010, color);
    Display_FillCircleQuarter(x + radius, y + h - radius, radius, 0b0001, color);
}
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

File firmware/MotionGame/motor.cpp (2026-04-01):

#include "motor.h"
#include <Arduino.h>
#include <math.h>

/* ================= 震动状态（供外部访问）================= */
bool motor_vibrating = false;
uint32_t motor_vibrate_deadline = 0;

/* ================= 状态变量 ================= */
static MotorState motor_a_state = MOTOR_STATE_STOP;
static MotorState motor_b_state = MOTOR_STATE_STOP;
static uint32_t vibrate_deadline = 0;

/* ================= 工具函数 ================= */
static void write_motor_a(MotorState state, uint8_t speed) {
    motor_a_state = state;
    
    switch (state) {
        case MOTOR_STATE_STOP:
            ledcWrite(MOTOR_A_IN1, 0);
            digitalWrite(MOTOR_A_IN2, LOW);
            break;
            
        case MOTOR_STATE_FORWARD:
            // IN1 = PWM (调速), IN2 = LOW (正转)
            ledcWrite(MOTOR_A_IN1, speed);
            digitalWrite(MOTOR_A_IN2, LOW);
            break;
            
        case MOTOR_STATE_BRAKE:
            // IN1 = HIGH (255), IN2 = HIGH (刹车)
            ledcWrite(MOTOR_A_IN1, 255);
            digitalWrite(MOTOR_A_IN2, HIGH);
            break;
    }
}

static void write_motor_b(MotorState state, uint8_t speed) {
    motor_b_state = state;
    
    switch (state) {
        case MOTOR_STATE_STOP:
            ledcWrite(MOTOR_B_IN3, 0);
            digitalWrite(MOTOR_B_IN4, LOW);
            break;
            
        case MOTOR_STATE_FORWARD:
            // IN3 = PWM (调速), IN4 = LOW (正转)
            ledcWrite(MOTOR_B_IN3, speed);
            digitalWrite(MOTOR_B_IN4, LOW);
            break;
            
        case MOTOR_STATE_BRAKE:
            // IN3 = HIGH (255), IN4 = HIGH (刹车)
            ledcWrite(MOTOR_B_IN3, 255);
            digitalWrite(MOTOR_B_IN4, HIGH);
            break;
    }
}

/* ================= 初始化 ================= */
void Motor_Init(void) {
    // 设置所有引脚为输出
    pinMode(MOTOR_A_IN1, OUTPUT);
    pinMode(MOTOR_A_IN2, OUTPUT);
    pinMode(MOTOR_B_IN3, OUTPUT);
    pinMode(MOTOR_B_IN4, OUTPUT);
    
    // 初始化 PWM 通道 (GPIO12, GPIO19)
    ledcAttach(MOTOR_A_IN1, MOTOR_PWM_FREQ, MOTOR_PWM_RES);
    ledcAttach(MOTOR_B_IN3, MOTOR_PWM_FREQ, MOTOR_PWM_RES);
    
    // 初始状态：停止
    Motor_Stop(MOTOR_BOTH);
    
    motor_vibrating = false;
    motor_vibrate_deadline = 0;
}

/* ================= 停止 ================= */
void Motor_Stop(MotorSelect motor) {
    if (motor == MOTOR_A || motor == MOTOR_BOTH) {
        write_motor_a(MOTOR_STATE_STOP, 0);
    }
    if (motor == MOTOR_B || motor == MOTOR_BOTH) {
        write_motor_b(MOTOR_STATE_STOP, 0);
    }
}

/* ================= 刹车 ================= */
void Motor_Brake(MotorSelect motor) {
    if (motor == MOTOR_A || motor == MOTOR_BOTH) {
        write_motor_a(MOTOR_STATE_BRAKE, 0);
    }
    if (motor == MOTOR_B || motor == MOTOR_BOTH) {
        write_motor_b(MOTOR_STATE_BRAKE, 0);
    }
}

/* ================= 正转调速 ================= */
void Motor_Forward(MotorSelect motor, uint8_t speed) {
    if (speed == 0) {
        Motor_Stop(motor);
        return;
    }
    
    if (motor == MOTOR_A || motor == MOTOR_BOTH) {
        write_motor_a(MOTOR_STATE_FORWARD, speed);
    }
    if (motor == MOTOR_B || motor == MOTOR_BOTH) {
        write_motor_b(MOTOR_STATE_FORWARD, speed);
    }
}

/* ================= 震动反馈 ================= */
void Motor_Vibrate(uint8_t speed) {
    Motor_Forward(MOTOR_BOTH, speed);
    motor_vibrating = true;
}

void Motor_VibrateShort(void) {
    Motor_Vibrate(HAPTIC_SPEED_MEDIUM);
    motor_vibrate_deadline = millis() + 50;
}

void Motor_VibrateMedium(void) {
    Motor_Vibrate(HAPTIC_SPEED_MEDIUM);
    motor_vibrate_deadline = millis() + 100;
}

void Motor_VibrateLong(void) {
    Motor_Vibrate(HAPTIC_SPEED_MEDIUM);
    motor_vibrate_deadline = millis() + 200;
}

/* ================= 非阻塞更新 ================= */
void Motor_Update(void) {
    if (motor_vibrating && millis() >= motor_vibrate_deadline) {
        Motor_Stop(MOTOR_BOTH);
        motor_vibrating = false;
    }
}

/* ================= 查询状态 ================= */
bool Motor_isRunning(void) {
    return (motor_a_state != MOTOR_STATE_STOP) || 
           (motor_b_state != MOTOR_STATE_STOP);
}

/* ================= 正弦波调速测试 ================= */
#define SINE_TEST_PERIOD_MS   2000    // 周期 2 秒
#define SINE_TEST_MAX_SPEED   255      // 最大速度

static bool sine_test_active = false;
static uint32_t sine_test_start = 0;

void Motor_TestSineWave(void) {
    if (!sine_test_active) {
        sine_test_active = true;
        sine_test_start = millis();
        Serial.println(">> 正弦波调速测试开始 (2秒周期)");
    }
    
    uint32_t elapsed = millis() - sine_test_start;
    float t = (float)(elapsed % SINE_TEST_PERIOD_MS) / SINE_TEST_PERIOD_MS;  // 0 ~ 1
    float sine_value = sin(t * 2 * PI);  // -1 ~ 1
    
    // 映射到速度 0-255 (去掉负半波，只正转)
    uint8_t speed = (uint8_t)((sine_value + 1.0f) / 2.0f * SINE_TEST_MAX_SPEED);
    
    Motor_Forward(MOTOR_BOTH, speed);
    
    // 每 500ms 打印一次状态
    static uint32_t last_print = 0;
    if (millis() - last_print > 500) {
        last_print = millis();
        Serial.print(">> 正弦波 t=");
        Serial.print(t, 2);
        Serial.print(" speed=");
        Serial.println(speed);
    }
}

void Motor_TestSineWave_Stop(void) {
    sine_test_active = false;
    Motor_Stop(MOTOR_BOTH);
    Serial.println(">> 正弦波测试停止");
}

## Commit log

2026-01-01 init: project structure and basic drivers
2026-01-19 基础模块、结构、菜单完成
2026-01-20 添加字符显示，优化菜单渲染
2026-02-17 添加硬件文件
    [BOM_Board1_Schematic1_2026-01-24.xlsx, BOM_四驱动_四驱动_2026-02-08.xlsx, P1.dxf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]
2026-02-17 feat: 添加平衡球游戏 + 云端接口框架
    - 新增 game_balance: 完整的体感平衡球游戏
    - 物理模拟（倾斜控制 + 摩擦力 + 碰撞反弹）
    - 计分系统（基础分 + 时间奖励）
    - 胜利判定和音效反馈
    - 新增 cloud_api: 云端接口框架（预留 WiFi/MQTT）
    - 单机/联网无缝切换（CLOUD_ENABLED 开关）
    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
2026-04-01 feat: 添加赛车游戏和统一反馈系统
    - 新增 game_race.cpp 伪3D赛车游戏
    - 新增 motor.cpp/h 震动马达驱动
    - 新增 buzzer.cpp/h 蜂鸣器驱动
    - 新增 output_feedback.cpp/h 统一反馈系统
    - 优化贪吃蛇和平衡球反馈效果
    [BOM_Board1_Schematic1_2026-01-24.xlsx, BOM_四驱动_四驱动_2026-02-08.xlsx, P1.dxf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]
2026-04-07 feat: add WiFi controller mode, theme system, hardware docs
    - Add wifi_controller module for PC keyboard simulation
    - UDP-based communication
    - Tilt-to-arrow mapping with shake-to-A
    - Add 6-color theme system with EEPROM persistence
    - Add hardware wiring documentation
    - Add PC-side UDP keyboard receiver (Python)
    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
    [器件表.xlsx]
